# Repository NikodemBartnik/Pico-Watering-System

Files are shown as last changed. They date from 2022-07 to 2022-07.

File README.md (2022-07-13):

## Video

IndyMill Final test (https://youtu.be/s-xkdfNeIVw)

Simple automated solar powered watering system for your garden based on cool and inexpensive [Raspberry Pi Pico](https://www.raspberrypi.com/products/raspberry-pi-pico/). 
Designed by [Nikodem Bartnik](https://www.youtube.com/nikodembartnik). 

Most important features of this system

  - Simplicity
  - Watering based on time adjusted with buttons and current setting diplayed with LEDs
  - Ability to adjust watering cycles per day (1-4) and watering time (2,4,6,8 minutes per cycle) both values can be edjusted in the code
  - Single sided PCB that's easy to make at home
  - 2 water level sensors, 2 pumps and 2 soil moisture sensors to run two separete systems for different parts of the garden
  - Pumps controlled with IRFZ44N MOSFETs
  - Easy to 3D print case for the system
  - Beginner friendly

## Open Source
This project is open source, feel free to build, modify adjust to your needs and don't forget to share the results with others! I welcome everyone to improve it and contribute to the project!

## Parts

| Name | Amazon |  Aliexpress  |
| --- | ---- | ---  |
| Raspberry Pi Pico | https://amzn.to/3O2GBdG | https://bit.ly/3c9K7FP |
| Solar panel and charger | https://amzn.to/3PqgpLp | https://bit.ly/3yDzbIe |
| Garden irrigation set | https://amzn.to/3uLS3DL | https://bit.ly/3c9sE0m |
| Battery | https://amzn.to/3ceAIx6 | - |
| Pump | https://amzn.to/3O74vF0 | https://bit.ly/3z0th5v |
| Water level sensor | https://amzn.to/3z16nL9 | https://bit.ly/3nVWZSD |
| IRFZ44N | https://amzn.to/3O1NyvJ | https://bit.ly/3aG8udU |
| LEDs | https://amzn.to/3yxl1Zj | https://bit.ly/3NZ0nXz | 
| Buttons | https://amzn.to/3z0r75T | https://bit.ly/3yD8UtK |

You will also need a PCB to solder all the components, [prefboard](https://amzn.to/3RsRubK) if you don't want to make a PCB or a [breadboard](https://amzn.to/3P7sjdo). PCB is designed to be machined on a CNC machine, the traces are a bit thicker than normal and it is single sided. You can also easily make it at home using different manufacturing techniques, of course ordering it from professional  manufacturers is also an option.

## Support
You can support my projects on [Patreon](https://www.patreon.com/nikodembartnik) and [PayPal](https://paypal.me/nikodembartnik).
Here is my online store with parts for [IndyMill](https://github.com/NikodemBartnik/IndyMill) a CNC machine that I designed.

***

You can also checkout WDCS (Watering and Data Collection System) mentioned in the video. It's a more sophisticated solution with more sensor that you probably don't even need :) I suggest to stick to the Pico version because it is much better!

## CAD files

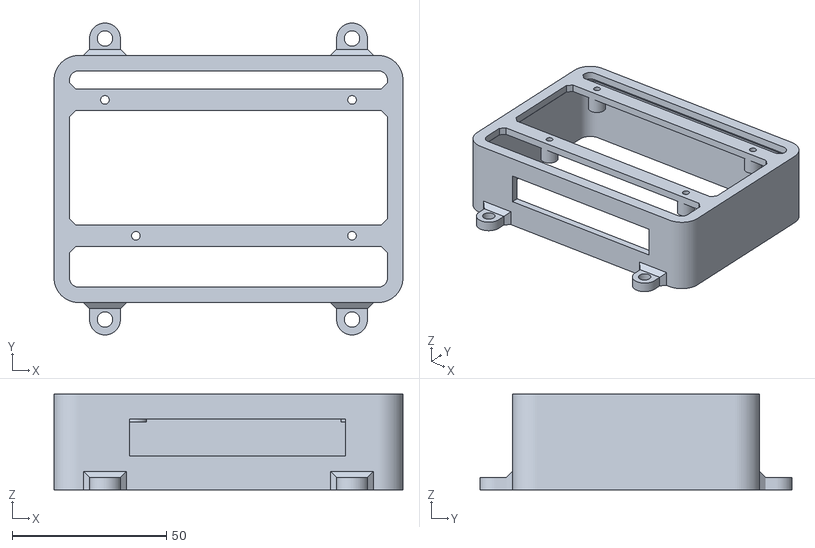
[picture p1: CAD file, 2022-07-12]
CAD/case4.stl
113.0 x 101.0 x 31.0

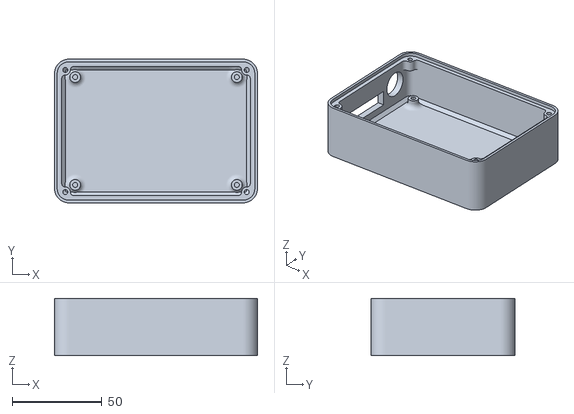
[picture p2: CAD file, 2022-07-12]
CAD/case1.stl
113.0 x 80.0 x 32.0

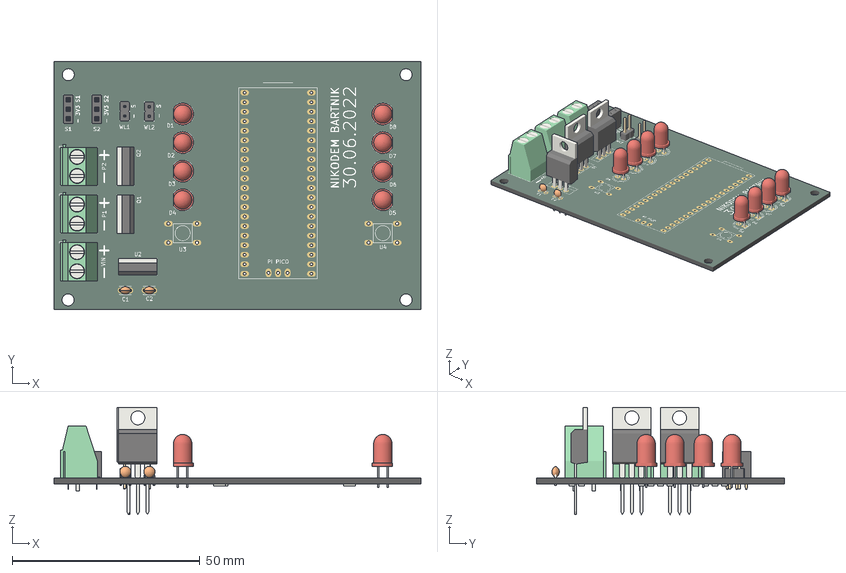
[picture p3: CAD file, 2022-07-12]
CAD/pcb.3mf
97.8 x 66.0 x 28.5 mm

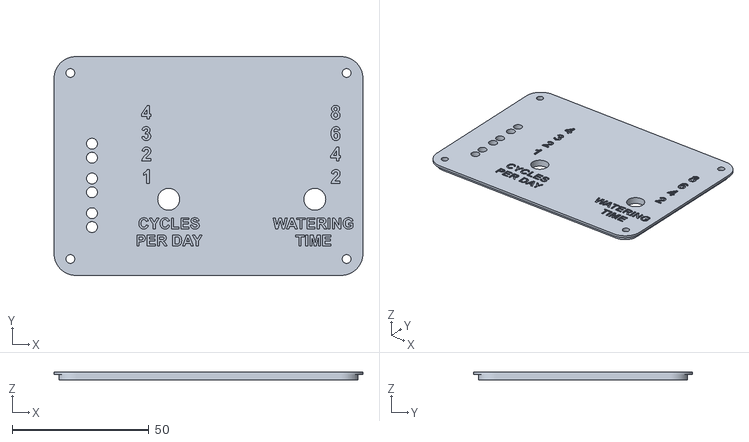
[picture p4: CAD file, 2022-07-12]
CAD/case2.stl
113.0 x 80.0 x 3.00

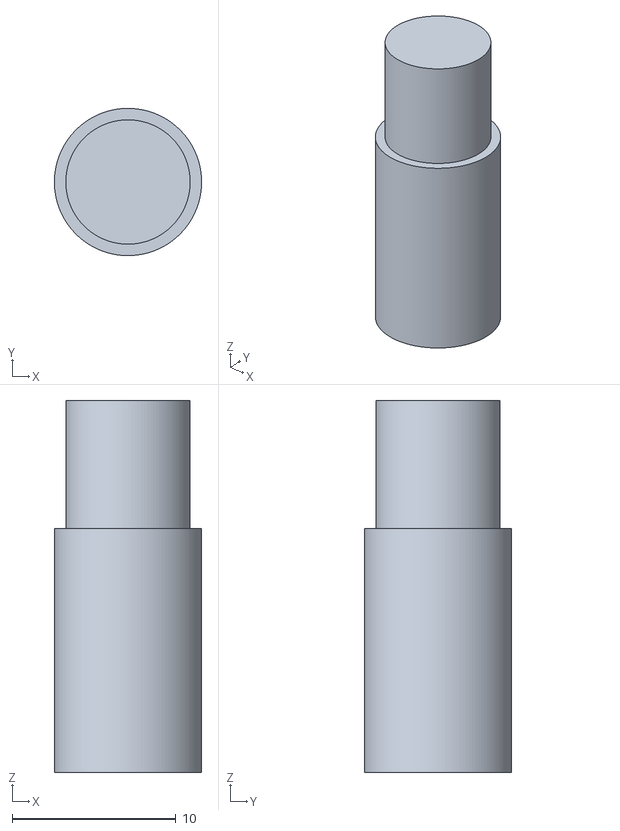
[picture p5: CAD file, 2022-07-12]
CAD/case3.stl
9.00 x 9.00 x 22.7

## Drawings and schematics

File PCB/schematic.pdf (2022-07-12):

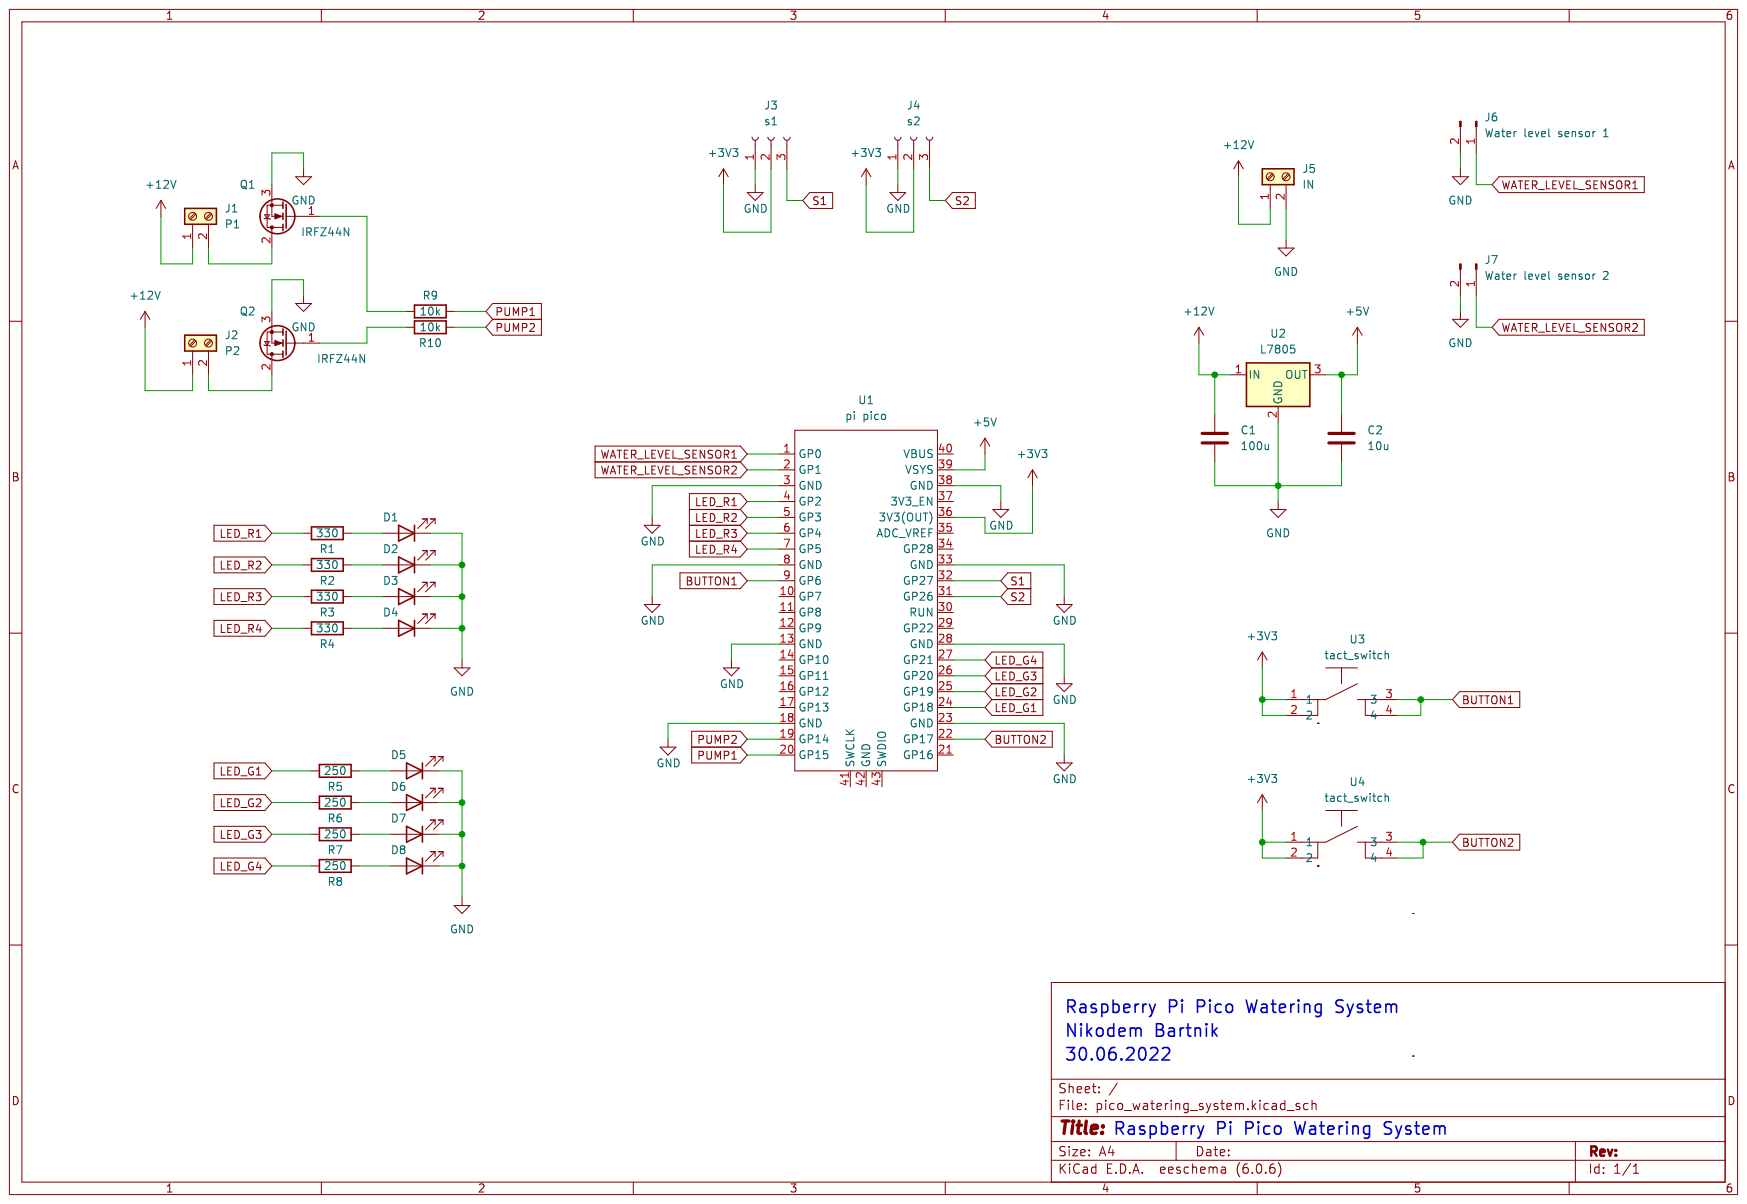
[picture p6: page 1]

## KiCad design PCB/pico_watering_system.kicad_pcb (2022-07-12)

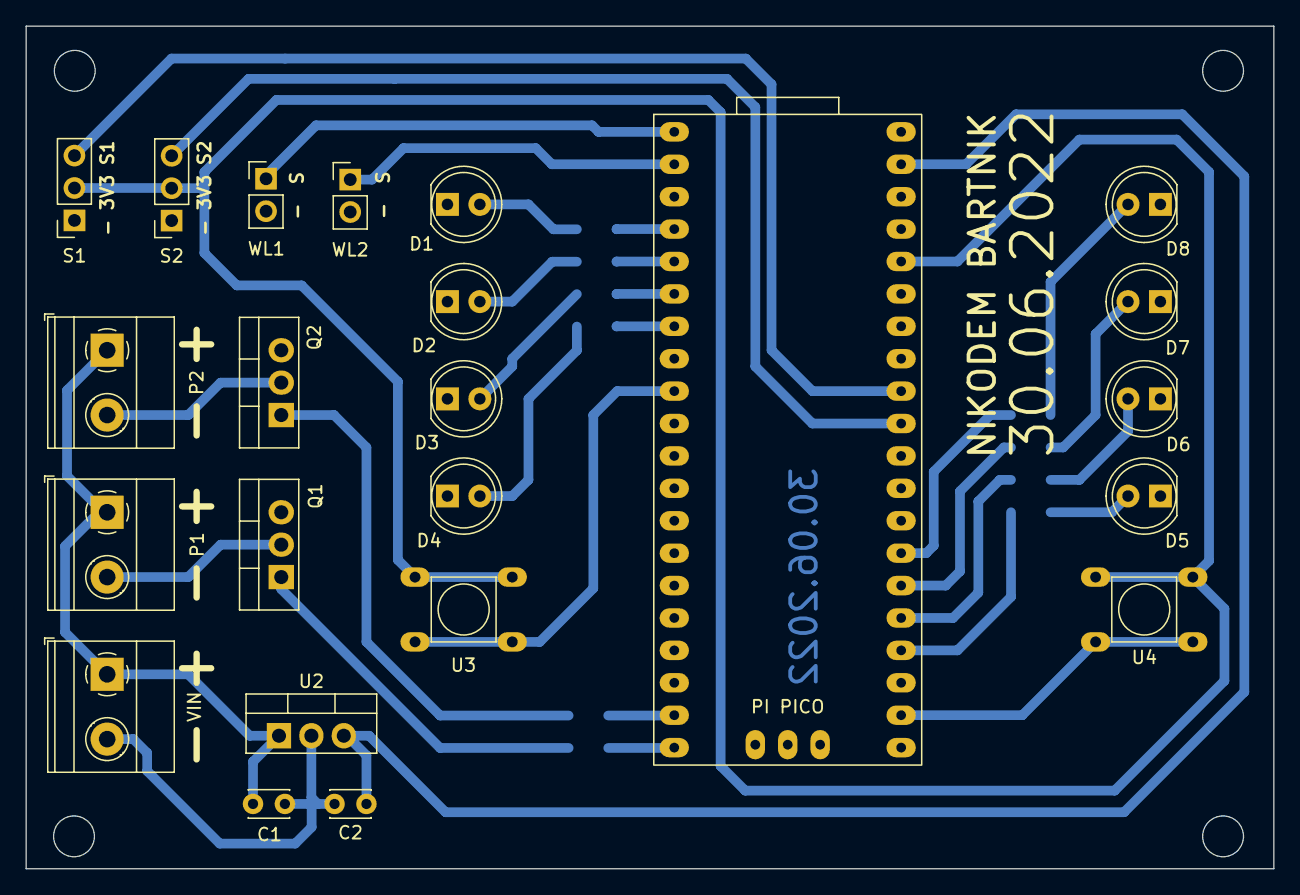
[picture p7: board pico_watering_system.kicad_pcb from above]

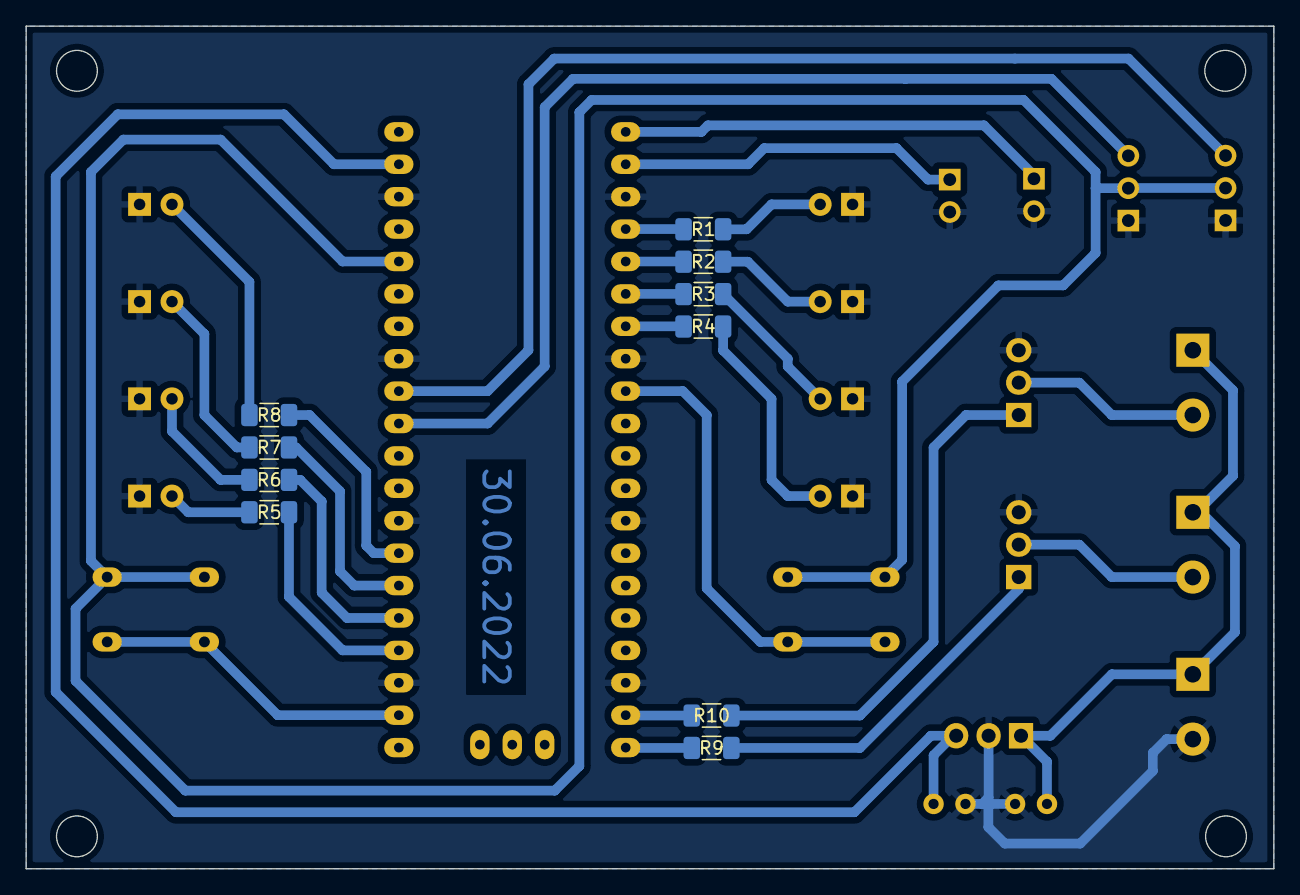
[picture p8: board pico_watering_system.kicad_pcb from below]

Board: 2 copper layers, 97.8 x 66.0 mm, 33 parts (10 on the bottom side), 32 nets.

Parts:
C1: 100u; C_Disc_D3.0mm_W2.0mm_P2.50mm
C2: 10u; C_Disc_D3.0mm_W2.0mm_P2.50mm
D1, D2, D3, D4, D5, D6, D7, D8: LED; LED_D5.0mm
P1: P1; TerminalBlock_Phoenix_MKDS-1,5-2-5.08_1x02_P5.08mm_Horizont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
P2: P2; TerminalBlock_Phoenix_MKDS-1,5-2-5.08_1x02_P5.08mm_Horizont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
PI PICO: pi pico; raspberry pi pico
Q1, Q2: IRFZ44N; TO-220-3_Vertical
R1, R2, R3, R4: 330; R_1206_3216Metric_Pad1.30x1.75mm_HandSolder
R5, R6, R7, R8: 250; R_1206_3216Metric_Pad1.30x1.75mm_HandSolder
R9, R10: 10k; R_1206_3216Metric_Pad1.30x1.75mm_HandSolder
S1: s1; PinSocket_1x03_P2.54mm_Vertical
S2: s2; PinSocket_1x03_P2.54mm_Vertical
U2: L7805; TO-220-3_Vertical
U3, U4: tact_switch
VIN: IN; TerminalBlock_Phoenix_MKDS-1,5-2-5.08_1x02_P5.08mm_Horizont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
WL1: Water level sensor 1; PinHeader_1x02_P2.54mm_Vertical
WL2: Water level sensor 2; PinHeader_1x02_P2.54mm_Vertical

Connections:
+3V3: PI PICO.36 (3V3(OUT)), S1.2, S2.2, U3.1, U3.2, U4.1, U4.2
+5V: C2.1, PI PICO.39 (VSYS), U2.3 (OUT)
+12V: C1.1, P1.1, P2.1, U2.1 (IN), VIN.1
BUTTON1: PI PICO.9 (GP6), U3.3, U3.4
BUTTON2: PI PICO.22 (GP17), U4.3, U4.4
GND: C1.2, C2.2, D1.1 (K), D2.1 (K), D3.1 (K), D4.1 (K), D5.1 (K), D6.1 (K), D7.1 (K), D8.1 (K), PI PICO.3 (GND), PI PICO.8 (GND), PI PICO.13 (GND), PI PICO.18 (GND), PI PICO.23 (GND), PI PICO.28 (GND), PI PICO.33 (GND), PI PICO.38 (GND), Q1.3 (S), Q2.3 (S), S1.1, S2.1, U2.2 (GND), VIN.2, WL1.2, WL2.2
LED_G1: PI PICO.24 (GP18), R5.1
LED_G2: PI PICO.25 (GP19), R6.1
LED_G3: PI PICO.26 (GP20), R7.1
LED_G4: PI PICO.27 (GP21), R8.1
LED_R1: PI PICO.4 (GP2), R1.1
LED_R2: PI PICO.5 (GP3), R2.1
LED_R3: PI PICO.6 (GP4), R3.1
LED_R4: PI PICO.7 (GP5), R4.1
unnamed: D1.2 (A), R1.2
unnamed: D2.2 (A), R2.2
unnamed: D3.2 (A), R3.2
unnamed: D4.2 (A), R4.2
unnamed: D5.2 (A), R5.2
unnamed: D6.2 (A), R6.2
unnamed: D7.2 (A), R7.2
unnamed: D8.2 (A), R8.2
unnamed: P1.2, Q1.2 (D)
unnamed: P2.2, Q2.2 (D)
unnamed: Q1.1 (G), R9.1
unnamed: Q2.1 (G), R10.1
PUMP1: PI PICO.20 (GP15), R9.2
PUMP2: PI PICO.19 (GP14), R10.2
S1: PI PICO.32 (GP27), S1.3
S2: PI PICO.31 (GP26), S2.3
WATER_LEVEL_SENSOR1: PI PICO.1 (GP0), WL1.1
WATER_LEVEL_SENSOR2: PI PICO.2 (GP1), WL2.1

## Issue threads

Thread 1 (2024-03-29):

Problem z kodem do raspberry pi pico

InfoMati18, 2024-03-29:
Traceback (most recent call last):
  File "<stdin>", line 25, in <module>
NameError: name 'Timer' isn't defined
kod z pliku:
#constants
PIN_PUMP_1 = 15
PIN_PUMP_2 = 14
PIN_LED_R_1 = 2
PIN_LED_R_2 = 3
PIN_LED_R_3 = 4
PIN_LED_R_4 = 5
PIN_LED_G_1 = 18
PIN_LED_G_2 = 19
PIN_LED_G_3 = 20
PIN_LED_G_4 = 21

PIN_BUTTON_1 = 6
PIN_BUTTON_2 = 17

PIN_WATER_LEVEL_SENSOR_1 = 0
PIN_WATER_LEVEL_SENSOR_2 = 1

WATERING_CYCLE_TIMES_ARRAY = [2, 4, 6, 8] #time in minutes

#global variables
selectionActive = True
dailyWateringCycles = 3
wateringCycleTime = 1 #choose from WATERING_CYCLE_TIMES
selectionTimer = Timer()
lastWatering = Timer.time()

pump1 = Pin(PIN_PUMP_1, Pin.OUT)
pump2 = Pin(PIN_PUMP_2, Pin.OUT)

ledR1 = Pin(PIN_LED_R_1, Pin.OUT)
ledR2 = Pin(PIN_LED_R_2, Pin.OUT)
ledR3 = Pin(PIN_LED_R_3, Pin.OUT)
ledR4 = Pin(PIN_LED_R_4, Pin.OUT)
ledG1 = Pin(PIN_LED_G_1, Pin.OUT)
ledG2 = Pin(PIN_LED_G_2, Pin.OUT)
ledG3 = Pin(PIN_LED_G_3, Pin.OUT)
ledG4 = Pin(PIN_LED_G_4, Pin.OUT)

button1 = Pin(PIN_BUTTON_1, Pin.IN, Pin.PULL_DOWN)
button2 = Pin(PIN_BUTTON_2, Pin.IN, Pin.PULL_DOWN)
wl1 = Pin(PIN_WATER_LEVEL_SENSOR_1, Pin.IN, Pin.PULL_UP)
wl2 = Pin(PIN_WATER_LEVEL_SENSOR_2, Pin.IN, Pin.PULL_UP)

def checkKeys():
    global selectionActive
    if(button1.value() or button2.value()):
        selectionActive = True
        selectionTimer.init(mode=Timer.ONE_SHOT, period=10000, callback=disableSelection)

def disableSelection(t):
    global selectionActive
    selectionActive = False
    ledR1.value(0)
    ledR2.value(0)
    ledR3.value(0)
    ledR4.value(0)
    ledG1.value(0)
    ledG2.value(0)
    ledG3.value(0)
    ledG4.value(0)
    saveSettings()
    selectionTimer.init(mode=Timer.PERIODIC, freq=0.1, callback=signOfLife)

def saveSettings():
    #saving settings
    try:
        os.remove('t.txt')
    except OSError:
        print("t.txt doesn't exists")
    try:
        os.remove('c.txt')
    except OSError:
        print("t.txt doesn't exists")

    f = open('t.txt', 'w+')
    f.write(str(wateringCycleTime))
    f.close()
    f = open('c.txt', 'w+')
    f.write(str(dailyWateringCycles))
    f.close()

def loadSettings():
    global wateringCycleTime, dailyWateringCycles
    try:
        f = open('t.txt')
        wateringCycleTime = int(f.read())
        print('wateringCycleTime', wateringCycleTime)
        f.close()
    except OSError:
        print("t.txt doesn't exists")
    try:
        f = open('c.txt')
        dailyWateringCycles = int(f.read())
        print('dailyWateringCycles', dailyWateringCycles)
        f.close()
    except OSError:
        print("c.txt doesn't exists")

def displayWateringTimes():
    if(selectionActive):
        ledR4.value(1) if wateringCycleTime >= 0 else ledR4.value(0)
        ledR3.value(1) if wateringCycleTime >= 1 else ledR3.value(0)
        ledR2.value(1) if wateringCycleTime >= 2 else ledR2.value(0)
        ledR1.value(1) if wateringCycleTime >= 3 else ledR1.value(0)

def displayWateringCycles():
    if(selectionActive):
        ledG1.value(1) if dailyWateringCycles >= 0 else ledG1.value(0)
        ledG2.value(1) if dailyWateringCycles >= 1 else ledG2.value(0)
        ledG3.value(1) if dailyWateringCycles >= 2 else ledG3.value(0)
        ledG4.value(1) if dailyWateringCycles >= 3 else ledG4.value(0)

def checkAndModifySettings():
    global wateringCycleTime, dailyWateringCycles
    if(button1.value()):
        time.sleep_ms(50)
        if(button1.value()):
            wateringCycleTime = (wateringCycleTime+1) if wateringCycleTime < 3 else 0
            displayWateringTimes()
            time.sleep_ms(200)

    if(button2.value()):
        time.sleep_ms(50)
        if(button2.value()):
            dailyWateringCycles = (dailyWateringCycles+1) if dailyWateringCycles < 3 else 0
            displayWateringCycles()
            time.sleep_ms(200)

def checkWatering():
    global lastWatering
    if((time.time() - lastWatering) > (86400/(dailyWateringCycles + 1))):
        wateringStart = time.time()
        if(checkWaterLevel()):
            pump1.value(1)
            while(time.time() - wateringStart < (WATERING_CYCLE_TIMES_ARRAY[wateringCycleTime]*60)):
                ledG1.value(1)
                time.sleep_ms(200)
                ledG1.value(0)
                time.sleep_ms(200)
            pump1.value(0)
        lastWatering = time.time()

def signOfLife(t):
    ledR1.value(1)
    time.sleep_ms(10)
    ledR1.value(0)
    print('sign of life')

def checkWaterLevel():
    return 0 if wl1.value() else 1

def checkWaterAndAlarm():
    if(checkWaterLevel() == 0):
        ledR4.value(1)
        time.sleep_ms(500)
        ledR4.value(0)
        time.sleep_ms(500)

#loading the settings from flash before entering the loop
loadSettings()
#disable LEDs after 10 seconds
selectionTimer.init(mode=Timer.ONE_SHOT, period=10000, callback=disableSelection)

while(1):
    checkKeys()
    checkWatering()
    if(selectionActive):
        checkAndModifySettings()
        displayWateringTimes()
        displayWateringCycles()
    else:
        checkWaterAndAlarm()

    time.sleep_ms(50)

NikodemBartnik, 2024-03-29:
Copy the complete code, you forgot the two lines at the top that import the necessary modules

Closed 2024-03-29.

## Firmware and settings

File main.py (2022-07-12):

from machine import Pin, ADC, Timer
import time, os

#constants
PIN_PUMP_1 = 15
PIN_PUMP_2 = 14
PIN_LED_R_1 = 2
PIN_LED_R_2 = 3
PIN_LED_R_3 = 4
PIN_LED_R_4 = 5
PIN_LED_G_1 = 18
PIN_LED_G_2 = 19
PIN_LED_G_3 = 20
PIN_LED_G_4 = 21

PIN_BUTTON_1 = 6
PIN_BUTTON_2 = 17

PIN_WATER_LEVEL_SENSOR_1 = 0
PIN_WATER_LEVEL_SENSOR_2 = 1

WATERING_CYCLE_TIMES_ARRAY = [2, 4, 6, 8] #time in minutes

#global variables
selectionActive = True
dailyWateringCycles = 3 
wateringCycleTime = 1 #choose from WATERING_CYCLE_TIMES
selectionTimer = Timer()
lastWatering = time.time()

pump1 = Pin(PIN_PUMP_1, Pin.OUT)
pump2 = Pin(PIN_PUMP_2, Pin.OUT)

ledR1 = Pin(PIN_LED_R_1, Pin.OUT)
ledR2 = Pin(PIN_LED_R_2, Pin.OUT)
ledR3 = Pin(PIN_LED_R_3, Pin.OUT)
ledR4 = Pin(PIN_LED_R_4, Pin.OUT)
ledG1 = Pin(PIN_LED_G_1, Pin.OUT)
ledG2 = Pin(PIN_LED_G_2, Pin.OUT)
ledG3 = Pin(PIN_LED_G_3, Pin.OUT)
ledG4 = Pin(PIN_LED_G_4, Pin.OUT)

button1 = Pin(PIN_BUTTON_1, Pin.IN, Pin.PULL_DOWN)
button2 = Pin(PIN_BUTTON_2, Pin.IN, Pin.PULL_DOWN)
wl1 = Pin(PIN_WATER_LEVEL_SENSOR_1, Pin.IN, Pin.PULL_UP)
wl2 = Pin(PIN_WATER_LEVEL_SENSOR_2, Pin.IN, Pin.PULL_UP)


def checkKeys():
    global selectionActive
    if(button1.value() or button2.value()):
        selectionActive = True
        selectionTimer.init(mode=Timer.ONE_SHOT, period=10000, callback=disableSelection)
        
def disableSelection(t):
    global selectionActive
    selectionActive = False
    ledR1.value(0)
    ledR2.value(0)
    ledR3.value(0)
    ledR4.value(0)
    ledG1.value(0)
    ledG2.value(0)
    ledG3.value(0)
    ledG4.value(0)
    saveSettings()
    selectionTimer.init(mode=Timer.PERIODIC, freq=0.1, callback=signOfLife)
    
    
def saveSettings():
    #saving settings
    try:
        os.remove('t.txt')
    except OSError:
        print("t.txt doesn't exists")
    try:
        os.remove('c.txt')
    except OSError:
        print("t.txt doesn't exists")
        
    f = open('t.txt', 'w+')
    f.write(str(wateringCycleTime))
    f.close()
    f = open('c.txt', 'w+')
    f.write(str(dailyWateringCycles))
    f.close()
    
def loadSettings():
    global wateringCycleTime, dailyWateringCycles
    try:
        f = open('t.txt')
        wateringCycleTime = int(f.read())
        print('wateringCycleTime', wateringCycleTime)
        f.close()
    except OSError:
        print("t.txt doesn't exists")
    try: 
        f = open('c.txt')
        dailyWateringCycles = int(f.read())
        print('dailyWateringCycles', dailyWateringCycles)
        f.close()
    except OSError:
        print("c.txt doesn't exists")

    
def displayWateringTimes():
    if(selectionActive):
        ledR4.value(1) if wateringCycleTime >= 0 else ledR4.value(0)
        ledR3.value(1) if wateringCycleTime >= 1 else ledR3.value(0)
        ledR2.value(1) if wateringCycleTime >= 2 else ledR2.value(0)
        ledR1.value(1) if wateringCycleTime >= 3 else ledR1.value(0)
        
        
def displayWateringCycles():
    if(selectionActive):
        ledG1.value(1) if dailyWateringCycles >= 0 else ledG1.value(0)
        ledG2.value(1) if dailyWateringCycles >= 1 else ledG2.value(0)
        ledG3.value(1) if dailyWateringCycles >= 2 else ledG3.value(0)
        ledG4.value(1) if dailyWateringCycles >= 3 else ledG4.value(0)
    

def checkAndModifySettings():
    global wateringCycleTime, dailyWateringCycles
    if(button1.value()):
        time.sleep_ms(50)
        if(button1.value()):
            wateringCycleTime = (wateringCycleTime+1) if wateringCycleTime < 3 else 0
            displayWateringTimes()
            time.sleep_ms(200)
    
    if(button2.value()):
        time.sleep_ms(50)
        if(button2.value()):
            dailyWateringCycles = (dailyWateringCycles+1) if dailyWateringCycles < 3 else 0
            displayWateringCycles()
            time.sleep_ms(200)
            
            

def checkWatering():
    global lastWatering
    if((time.time() - lastWatering) > (86400/(dailyWateringCycles + 1))):
        wateringStart = time.time()
        if(checkWaterLevel()):
            pump1.value(1)
            while(time.time() - wateringStart < (WATERING_CYCLE_TIMES_ARRAY[wateringCycleTime]*60)):
                ledG1.value(1)
                time.sleep_ms(200)
                ledG1.value(0)
                time.sleep_ms(200)
            pump1.value(0)
        lastWatering = time.time()
        
        
def signOfLife(t):
    ledR1.value(1)
    time.sleep_ms(10)
    ledR1.value(0)
    print('sign of life')
    
def checkWaterLevel():
    return 0 if wl1.value() else 1


def checkWaterAndAlarm():
    if(checkWaterLevel() == 0):
        ledR4.value(1)
        time.sleep_ms(500)
        ledR4.value(0)
        time.sleep_ms(500)
        

#loading the settings from flash before entering the loop
loadSettings()
#disable LEDs after 10 seconds
selectionTimer.init(mode=Timer.ONE_SHOT, period=10000, callback=disableSelection)

while(1):
    checkKeys()
    checkWatering()
    if(selectionActive):
        checkAndModifySettings()
        displayWateringTimes()
        displayWateringCycles()
    else:
        checkWaterAndAlarm()
        
    time.sleep_ms(50)
